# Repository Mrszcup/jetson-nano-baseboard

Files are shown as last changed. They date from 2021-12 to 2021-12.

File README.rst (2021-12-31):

=======================================
Antmicro's Open Source Jetson Baseboard
=======================================

Copyright (c) 2020-2021 `Antmicro <https://www.antmicro.com>`_

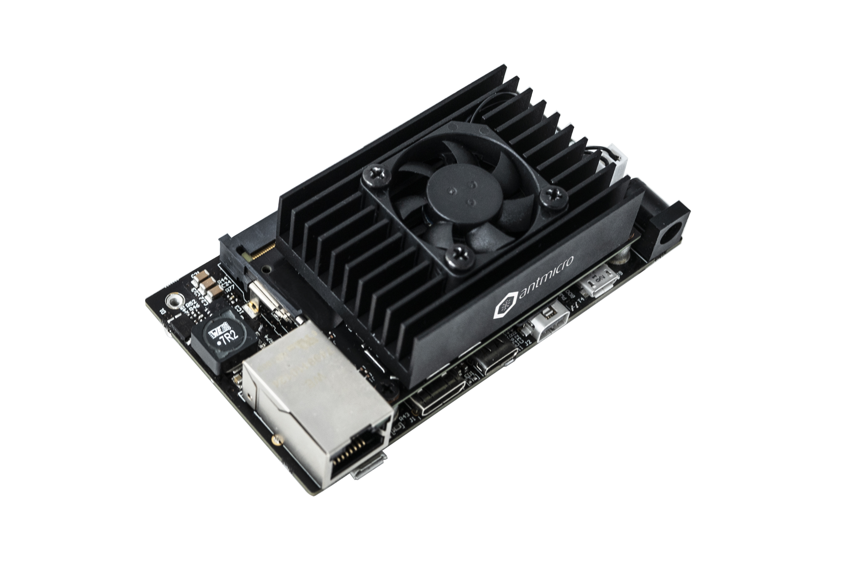
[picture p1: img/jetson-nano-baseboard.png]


Overview
========

This repository contains open hardware design files for a baseboard supporting the NVIDIA Jetson Nano, Xavier NX and TX2 NX SoMs. It's been created by `Antmicro <https://antmicro.com>`_, a custom hardware, software and AI engineering company and NVIDIA' Jetson ecosystem partner.
The board can be interfaced with MIPI CSI-2 video devices through a unified Flexible Flat Cable (FFC) connector, supporting up to 4 sensors in a 2-lane configuration or 3 sensors in a 4-lane configuration.
Please refer to the ``Jetson Nano OEM Product Design Guide`` for more details regarding the supported CSI lane mappings.

The baseboard, its custom variants designed by Antmicro per customer's specification, and essential accessories can be purchased from `Capable Robot Components <https://capablerobot.com/products/nx-baseboard/>`_.

Repository structure:
---------------------

The main repository directory contains the KiCad design files, LICENSE and README.
The remaining files are stored in the following directories:

* ``img`` - contains graphics for this README
* ``doc`` - contains generated schematics and other documentation

Key features
============

* Jetson Nano / Xavier NX / TX2 NX SO-DIMM connector
* Gigabit Ethernet RJ45 connector
* Micro USB debug connector
* USB-C DFP (Host) port
* Mini HDMI video output interface
* Mini DisplayPort video output interface
* 2x 50-pin FFC connectors exposing up to 4 MIPI CSI-2 camera interfaces
* M.2 (key M) connector exposing PCIe x4 interface
* RTC battery backup
* EEPROM for storing board ID/SN

The PCB project files were prepared in KiCad 5.1.x

Board layout & dimensions
=========================

The picture below presents a general layout of the PCB with marked I/O interfaces.

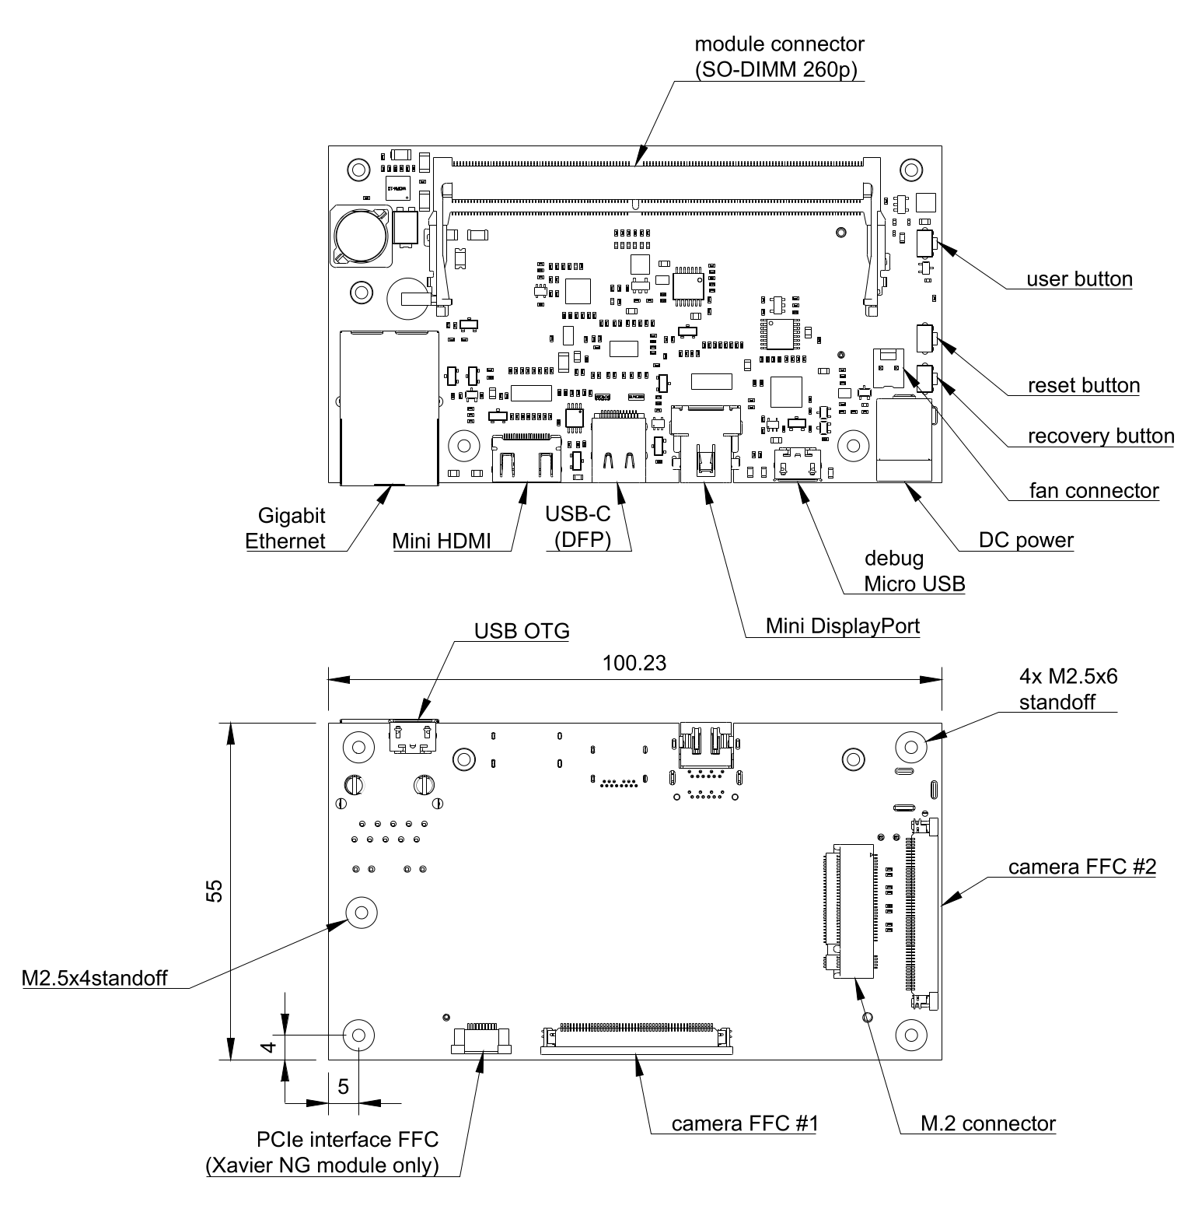
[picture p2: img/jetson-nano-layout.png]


Getting started
===============

The board can be produced and assembled using the provided design files.
Please take a look at the mechanical layers for more information regarding the PCB stackup recommended for fabrication.
The board can be powered by a voltage in the 6-36VDC range.
It is recommended to use a 12V 2A DC supply to power the board.
The board has an integrated power sequencer that starts the module automatically right after applying power supply.

BSP
---

The baseboard's I/O interfaces are supported in the standard `Linux for Tegra (L4T) BSPs <https://developer.nvidia.com/embedded/linux-tegra>`_ provided by NVIDIA for Jetson Nano / Xavier NX / TX2 NX. The BSP should work with the Open Source Jetson Baseboard out of the box. However, to use the baseboard with various cameras and other accessories you may need to make modifications. If you plan to use the board with Allied Vision `Alvium <https://www.alliedvision.com/en/products/embedded-vision-solutions/alvium-camera-modules-for-embedded-and-machine-vision-applications.html>`_ image sensors, there is a ``linux-patches`` directory, which contains patch files that add support for the Allied Vision cameras for this baseboard with the Jetson Nano NX module.
The patches are named with the L4T release and can be applied to corresponding branches of the Linux `repository <https://github.com/alliedvision/linux_nvidia_jetson>`_ released by Allied Vision. 
Antmicro's services involve BSP development so you can hire us to the necessary modifications for you.

You can use the USB OTG interface connector to upload a BSP image to a SoM inserted into the baseboard.

Debug UART connection
---------------------

Most of the debug messages are provided through the serial console.
The board includes an FTDI chip providing the UART interface to the host PC.
Please refer to the schematic sheets for more details.
The default debug UART channel is accessible through ``/dev/ttyUSB0`` (assuming that there are no other FTDI units connected to your PC).
The default baudrate for serial debug connection is 115200 baud with an 8-bit transmission, 1 stop bit and with no flow control.

Revision info
=============

The latest revision of the PCB includes the following changes and amendments:

* Introduced an 8-layer PCB stackup for a better separation of PCIe lanes
* Rotated the M.2 connector by 180 degrees to keep it away from the on-board DC/DC
* Changed the stacking height of the M.2 connector
* Simplified the M.2 supporting circuitry
* Exposed the ``CSI-G`` and ``PCIE1`` interfaces on the `Jetson Xavier NX <https://developer.nvidia.com/embedded/jetson-xavier-nx>`_
* Updated FAN control circuitry
* Changed GPIO assignment for camera-triggering signals
* Optimized board cutout for the DisplayPort connector
* Fine-tuned selected footprints to improve the reliability of the reflow soldering
* Changed power sequencing of the on-board DC/DC converters
* Fixed ``TPD8S009`` footprint
* Removed MicroSD card socket
* Updated ``USBC_VBUS`` control circuitry
* Added EEPROM for SN/ID storage

Please check the `releases <https://github.com/antmicro/jetson-nano-baseboard/releases>`_ for a brief summary of major changes introduced in previous revisions.

License
=======

`Apache-2.0 <LICENSE>`_

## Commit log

2021-10-03 DCDC passives copied
    [supply.sch]
2021-10-03 Update PCB with shematic changes
2021-10-04 Clean artefaccs, clean space for new DCDC
    [interfaces.sch, jetson-nano-baseboard.sch, som.sch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]
2021-10-04 Change HDMI connector on schematic
    [display.sch]
2021-10-04 Change HDMI connector on PCB
2021-10-04 Clean copied parts
    [display.sch]
2021-10-05 Changed package of SN74LV1T125 to SOT32
    [display.sch]
2021-10-05 Changed DP connector to micro HDMI on schematic
    [display.sch]
2021-10-06 DCDC placement, wiring of HDMI
2021-10-06 Replace NCP380HS with AP22652W6-7
    [usb-debug.sch]
2021-10-06 Move items to fit in borders
    [usb-debug.sch]
2021-10-06 Change TPD2E009DBZR with PESD2USB5UV-TR on schematic
    [display.sch, usb-debug.sch]
2021-10-06 Rotate D9 to fit connections
    [usb-debug.sch]
2021-10-06 Update TPD2E009DBZR to PESD2USB5UV-TR on PCB
2021-10-07 Replace 5V0 and 3V3 DCDC
    [supply.sch]
2021-10-07 Fix symbols, change DCDCC output capacitors to 0805
    [supply.sch]
2021-10-07 Disconnect pin 3 and 12 of LM604x0. Based on layout from datasheet
    [supply.sch]
2021-10-16 Cleanup wire stubs and artifacts
2021-10-19 Update comments, move things around on PCB
    [csi.sch, supply.sch]
2021-10-19 Move ethernet connector closet to the edge. Loclib
    [csi.sch, display.sch, interfaces.sch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]
2021-10-19 Fix traces after moving ethernet
2021-11-10 Change I2C mux
    [csi.sch, som.sch]
2021-11-10 Rework 3V3 and 5V DCDC on schematic, layout 3V3 DCDC
    [csi.sch, supply.sch]
2021-11-12 Layout 5V DCDC, check traces, fix ffab references size
2021-11-16 Change fan design to match Nvidia. Change user button and led pins
    [display.sch, som.sch, supply.sch]
2021-11-16 Move silks back into PCB
2021-11-16 Move OSHW logo away from track
2021-12-08 Replace ethernet connector, fix traces and tuning
    [interfaces.sch, usb-debug.sch]
2021-12-09 Change PESD2USB5UV-TR and TPD4E05U06_PASS to TPD4E05U06QDQARQ1
    [display.sch, usb-debug.sch]
2021-12-09 TLV70018DCKT -> TPS7A0518PDBVT
    [display.sch, usb-debug.sch]
2021-12-09 MDT580M01001 -> 1-2199230-6
    [interfaces.sch]
2021-12-09 9774040151 -> 9774025151
    [interfaces.sch]
2021-12-09 742792022 -> 74279221100
    [som.sch, supply.sch]
2021-12-12 Annotate parts
    [display.sch, interfaces.sch, som.sch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]
2021-12-12 Import changes to PCB, place J8, SP7 and add 3d model of 2280 NVMe
2021-12-12 Place IC1, improve USB_DEBUG traces
2021-12-12 Change connections to simplify routing
    [display.sch, usb-debug.sch]
2021-12-12 Update Ethernet symbol and footprint
    [interfaces.sch]
2021-12-12 Place TSVs, update ethernet footprint
2021-12-16 Remove DP connector and TSVs
    [display.sch]
2021-12-16 Add global labels for DP/HDMI signals
    [display.sch]
2021-12-16 Add global labels for DP/HDMI AUX signals
    [display.sch]
2021-12-16 Saving changes for later work
    [interfaces.sch, som.sch, usb-debug.sch]
2021-12-17 Connect PCIe and USB traces, fixing routing problems
2021-12-17 Route traces to new connector
2021-12-17 Reroute part of the traces
2021-12-17 Remove rejected ethernet ports
    [interfaces.sch]
2021-12-17 Fix 3V3 traces near NVMe connector
2021-12-17 Change 3V3 and Vin pins on J2 connector to simplify routing
    [interfaces.sch]
2021-12-17 Wire signals to debug USB-C connector
    [usb-debug.sch]
2021-12-17 Place 3V3 DCDC, debug USB circuitry
2021-12-20 Route 3V3 regulator, import coloured NVMe connector model
2021-12-20 Clear area under USB OTG connector
2021-12-20 Connect OTG USB and Ethernet on schematic
    [interfaces.sch, usb-debug.sch]
2021-12-20 Route status leds
2021-12-20 Change connections to TSV for easier routing
    [display.sch]
2021-12-21 Add b2b connector for POE signals
    [interfaces.sch]
2021-12-21 Add b2b POE connector to PCB
2021-12-21 Connect spacer to GND
    [som.sch]
2021-12-21 Update power planes, fix DRC
2021-12-21 Silks cleanup, minor fixes in traces
2021-12-31 Rearrange directory structure
    [CSI.SchDoc, Display.SchDoc, ID-Serial.SchDoc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]
